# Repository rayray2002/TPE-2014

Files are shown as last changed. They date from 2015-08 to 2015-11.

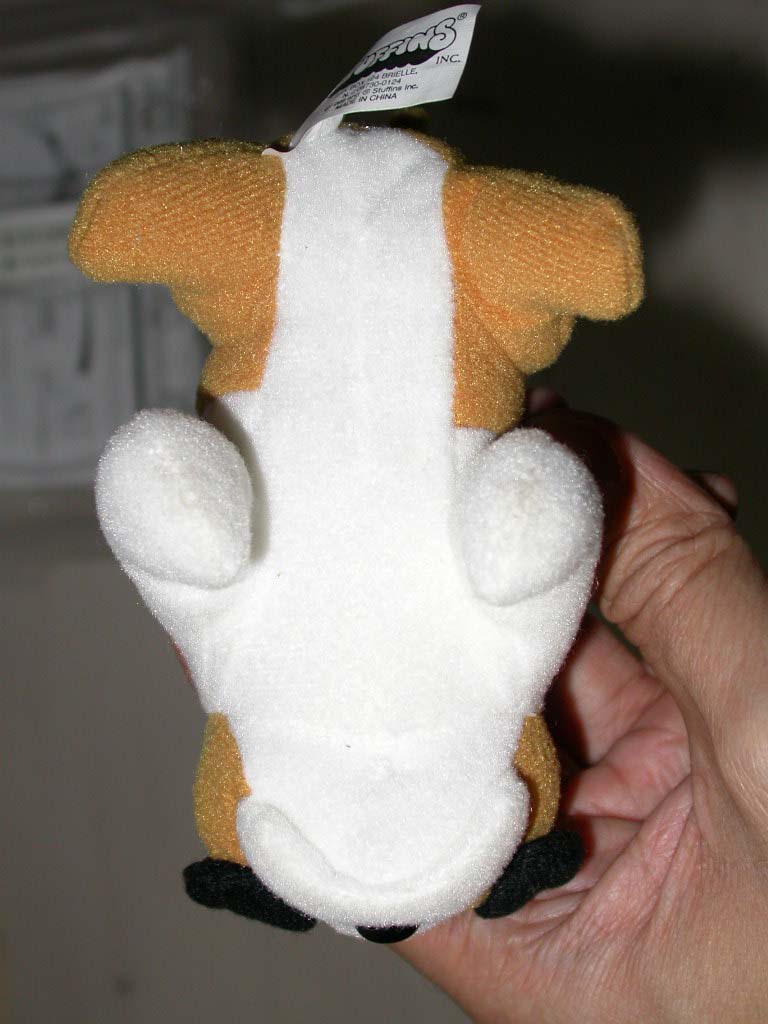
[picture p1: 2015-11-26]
3D/doggie/images/doggie_bottom.jpg

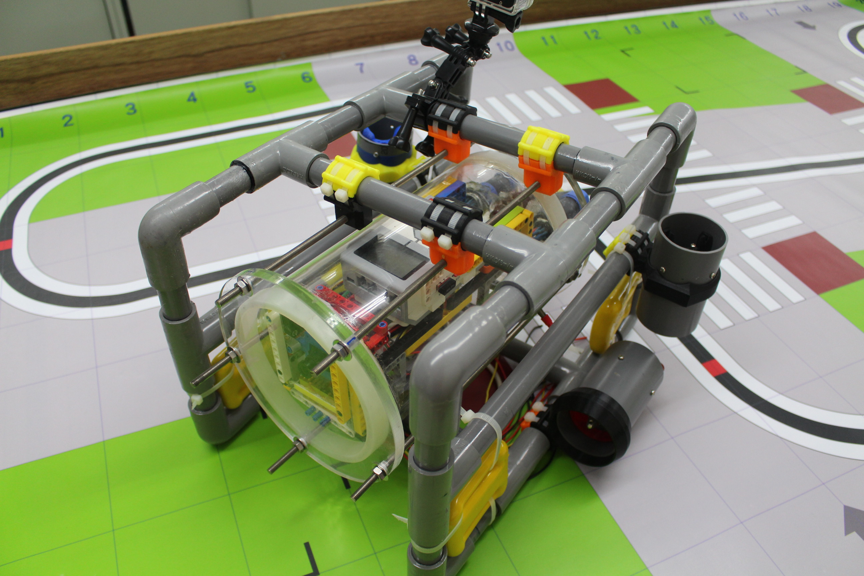
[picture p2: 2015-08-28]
document/images/IMG_3896.JPG

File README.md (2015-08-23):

# TPE-2014

TODO:
1. poster - 3 pages, architecture, include ev3dev, edison, arduino
2. software - pyserial, remote control,
3. hardware 

----
picture  
MINDMAP - 方法論
硬體架構圖
系統架構圖
功能流程圖
電路圖 - ev3

rov照片
intel edison照片
遙控介面圖

重點:
pwm, rc ppm, ev3 pin, 電壓和電流
7407 - 遇到的問題
uart, between ev3 edison, ev3 arduino pro mini
i2c, mpu9150 遇到 RTIMU
intel edison
  webserver
  wsgi
  javascript, html

結構
　　樂高, 3D print, 氣密, 電線安排, pvc管(切,合)？
  pvc管包壓克力管

  遇到的問題

  無法固定
  空間不足

解決

  用3dprinter印基座固定
  用洞洞板把麵包版上的元件焊得更小
  把板子換成arduino pro mini

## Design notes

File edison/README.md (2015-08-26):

UART set GPIO mode
https://communities.intel.com/thread/55790

echo 214 > /sys/class/gpio/export 2>&1
echo high > /sys/class/gpio/gpio214/direction
echo low > /sys/class/gpio/gpio214/direction
 
echo 131 > /sys/class/gpio/export 2>&1
echo mode1 > /sys/kernel/debug/gpio_debug/gpio131/current_pinmux
echo 249 > /sys/class/gpio/export 2>&1
echo high > /sys/class/gpio/gpio249/direction
echo 1 > /sys/class/gpio/gpio249/value
echo 217 > /sys/class/gpio/export 2>&1
echo high > /sys/class/gpio/gpio217/direction
echo 1 > /sys/class/gpio/gpio217/value
echo out > /sys/class/gpio/gpio131/direction
echo 0 > /sys/class/gpio/gpio131/value

echo 130 > /sys/class/gpio/export 2>&1
echo mode1 > /sys/kernel/debug/gpio_debug/gpio130/current_pinmux
echo 248 > /sys/class/gpio/export 2>&1
echo low > /sys/class/gpio/gpio248/direction
echo 0 > /sys/class/gpio/gpio248/value
echo 216 > /sys/class/gpio/export 2>&1
echo in > /sys/class/gpio/gpio216/direction
echo in > /sys/class/gpio/gpio130/direction
 
echo high > /sys/class/gpio/gpio214/direction

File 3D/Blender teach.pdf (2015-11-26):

# Blender教學講義

# Blender新手入門

### 1. 使用說明 2. Blender 介面 3. 使用者選單 4. 視角切換指令 5. 常用快速鍵

# 基礎模型建立

### 1. 新增物件 2. 編輯物件 3. 材質介面 4. 燈光介面 5. 渲染輸出

# 進階建模：高腳杯

### 1. 建立背景參考圖 2. 製作模型 3. 物件編修功能 4. 圖層管理 5. 透明材質 6. 鏡像材質與環境紋理 7. 燈光與陰影設置

# Blender新手入門

# １.使用說明

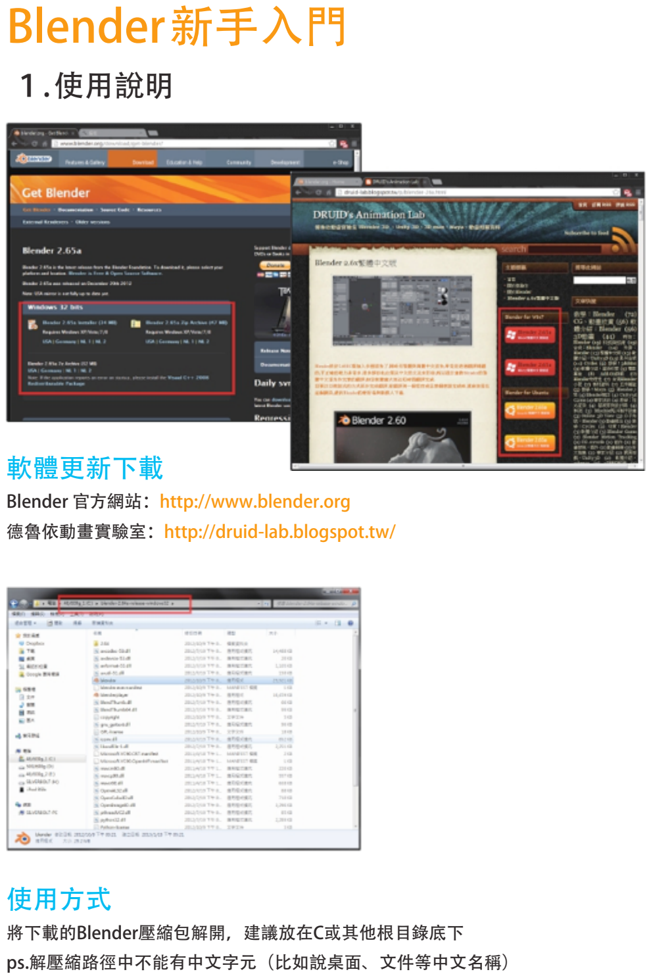
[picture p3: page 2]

## 軟體更新下載

Blender 官方網站：http://www.blender.org德魯依動畫實驗室：http://druid-lab.blogspot.tw/

## 使用方式

將下載的Blender壓縮包解開，建議放在C或其他根目錄底下 ps.解壓縮路徑中不能有中文字元（比如說桌面、文件等中文名稱）

# Blender新手入門

# 2.Blender介面

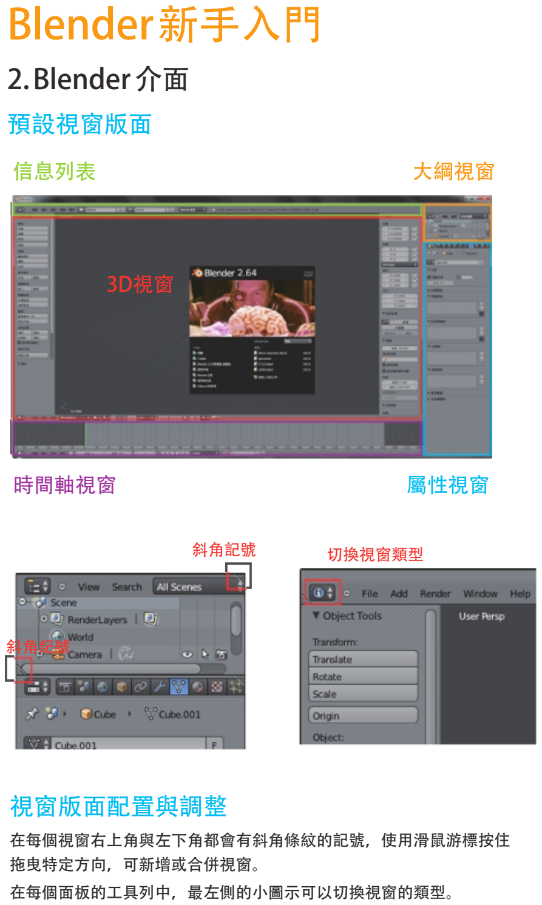
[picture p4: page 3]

## 預設視窗版面

信息列表 | 大綱視窗

### 3D視窗

時間軸視窗 | 屬性視窗
斜角記號 | 切換視窗類型

斜角記號

## 視窗版面配置與調整

在每個視窗右上角與左下角都會有斜角條紋的記號，使用滑鼠游標按住 拖曳特定方向，可新增或合併視窗。
在每個面板的工具列中，最左側的小圖示可以切換視窗的類型。

# Blender新手入門

# 3.使用者選單

## 開啟使用者選單

file（檔案）→ User Preferences（使用者設定）

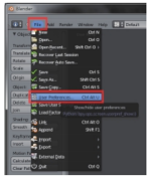
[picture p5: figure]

## 使用者選單設定

中文化設定

System（系統）→ 勾選 International Fonts（多國語言）
→ 選擇 Language（ 語系）→ Traditional Chinese（繁體中文）

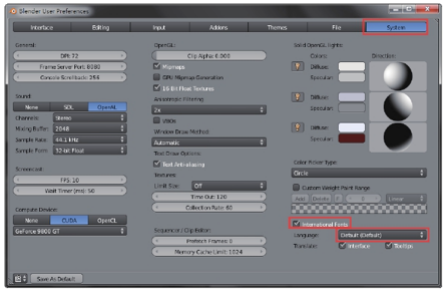
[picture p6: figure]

# Blender新手入門

# ４.視角切換指令

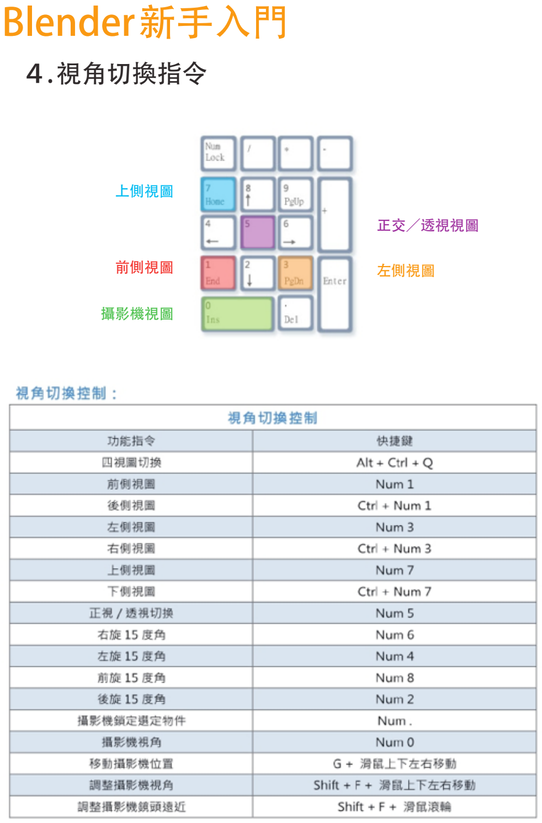
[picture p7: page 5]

上側視圖

前側視圖

攝影機視圖

正交／透視視圖

左側視圖

# Blender新手入門

# ５.常用快速鍵

開新檔案
開啟舊檔
儲存檔案
令存新檔
附加檔案
增加物件選單
複製物件
復原上一動作
重複前一動作
顯示／隱藏視窗工具架
顯示／隱藏視窗屬性選單
選取
移動
旋轉
縮放
單軸向移動、旋轉、縮放
雙軸向移動、旋轉、縮放
合併物件
子父關係
物件／編輯模式切換
全選／取消全選
反選
框選
複選
筆刷選取
增加選取
減少選取
選取環狀邊緣
區域影響切換
實體／線框顯示切換
擠出
刪除
環形切割
橋接點、線
增加點、線、面至游標位置
渲染圖像
顯示／隱藏渲染視窗
移動至圖層

Ｃtrl + N
F1、Ctrl + O
Ctrl + S
F2、Ctrl + Shift + S
Shift + F1
Shift + A
Shift + D
Ctrl + Z
Shift + R
T
N
滑鼠右鍵
G
R
S
啟用G、R、S狀態下，輸入對應的XYZ軸向
啟用G、R、S狀態下，輸入Shift + 不對應的XYZ軸向 Ctrl + J
Ctrl + P
Tab
A
Ctrl + I
輸入B後、滑鼠左鍵拖曳範圍
按住Shift、滑鼠右鍵加選目標
C
按住Ctrl、輸入+號
按住Ctrl、輸入-號
Alt + 滑鼠右鍵選取
O
Z
E
X、Delete
Ctrl + R
F
Ctrl + 滑鼠左鍵指定位置
F12
F11
M

# 基礎模型建立

# 1.新增物件

## 增加選單

信息列 → 增加 → 網面 → 多邊形物件

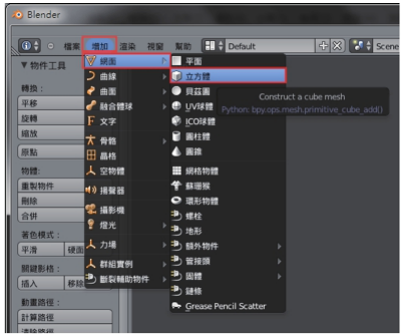
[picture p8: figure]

## 增加選單快速鍵

在3D視窗中輸入 Shift + A 可打開增加選單

# 基礎模型建立

# 2.編輯物件

## 編輯模式

3D視窗工具列 → 物體模式 → 編輯模式

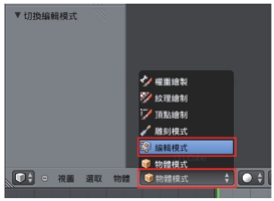
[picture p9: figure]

## 切換模式快速鍵

在3D視窗中輸入 Tab 可切換物體／編輯模式

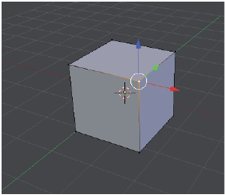
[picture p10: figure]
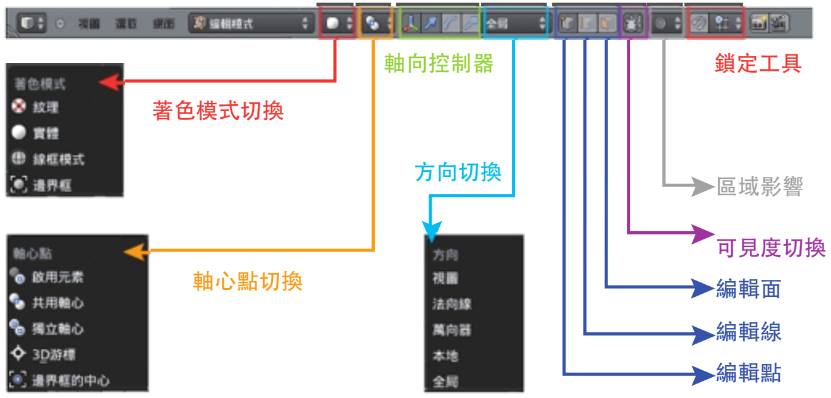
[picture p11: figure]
軸向控制器; 著色模式切換; 方向切換; 軸心點切換; 鎖定工具; 區域影響; 可見度切換; 編輯面; 編輯線; 編輯點

# 基礎模型建立

# 3.材質介面

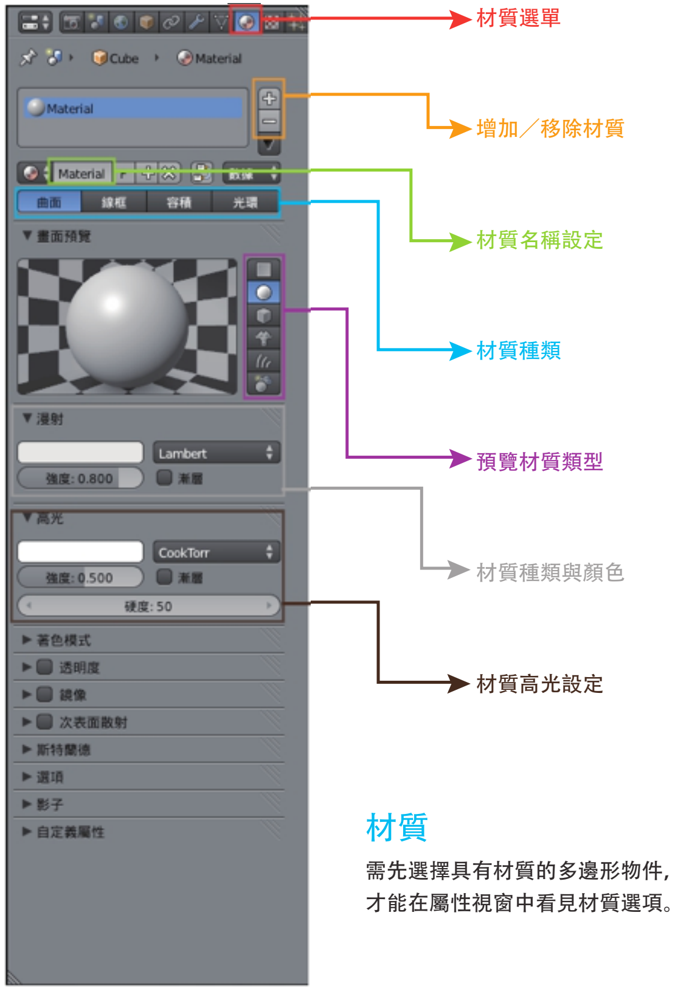
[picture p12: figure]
材質選單; 增加／移除材質; 材質名稱設定; 材質種類; 預覽材質類型; 材質種類與顏色; 材質高光設定; 需先選擇具有材質的多邊形物件，; 才能在屬性視窗中看見材質選項。

# 基礎模型建立

# 4.燈光介面

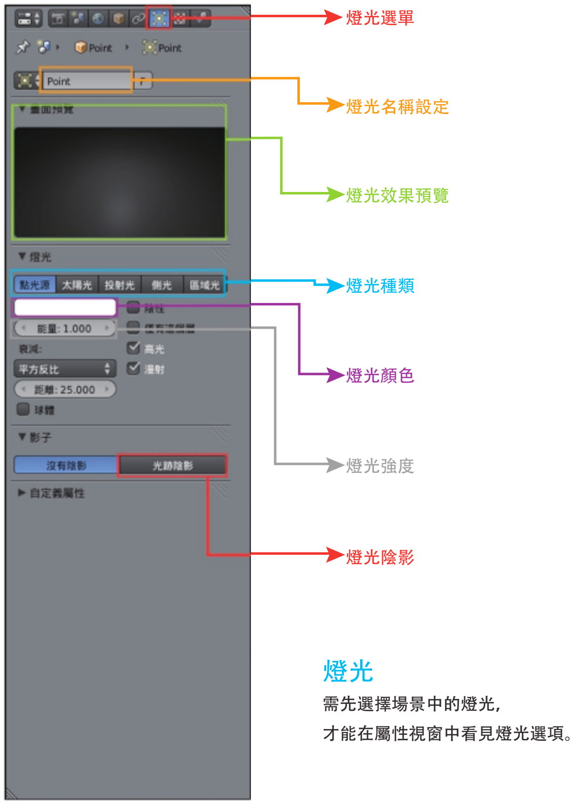
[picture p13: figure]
燈光選單; 燈光名稱設定; 燈光效果預覽; 燈光種類; 燈光顏色; 燈光強度; 燈光陰影; 需先選擇場景中的燈光，; 才能在屬性視窗中看見燈光選項。

# 基礎模型建立

# ５.渲染輸出

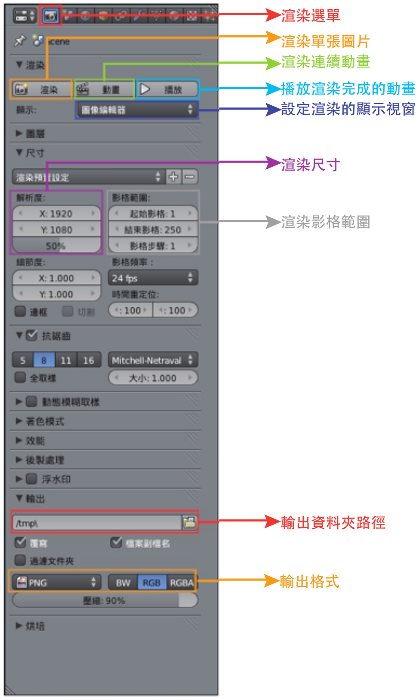
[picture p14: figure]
渲染選單; 渲染單張圖片 渲染連續動畫; 播放渲染完成的動畫 設定渲染的顯示視窗; 渲染尺寸; 渲染影格範圍; 輸出資料夾路徑; 輸出格式

# 進階建模：高腳杯

# 1.建立背景參考圖

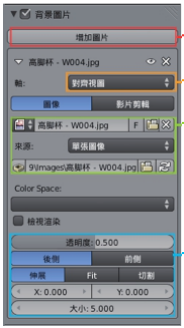
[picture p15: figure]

增加背景圖片

對齊類型

背景圖對應的檔名與資料夾路徑

圖片透明度、位置、大小調整

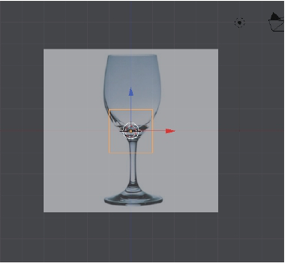
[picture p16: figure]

# 進階建模：高腳杯

# 2.製作模型

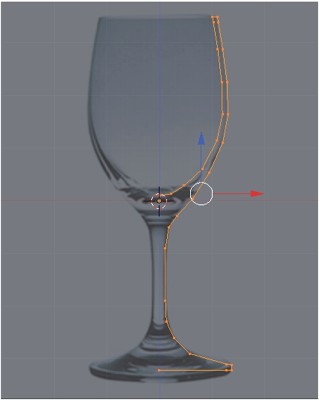
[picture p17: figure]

## 製作外型

在編輯模式中，以Ｘ軸向０為分隔線，製作半個模型的輪廓。

# 進階建模：高腳杯

# 3.物件編修功能

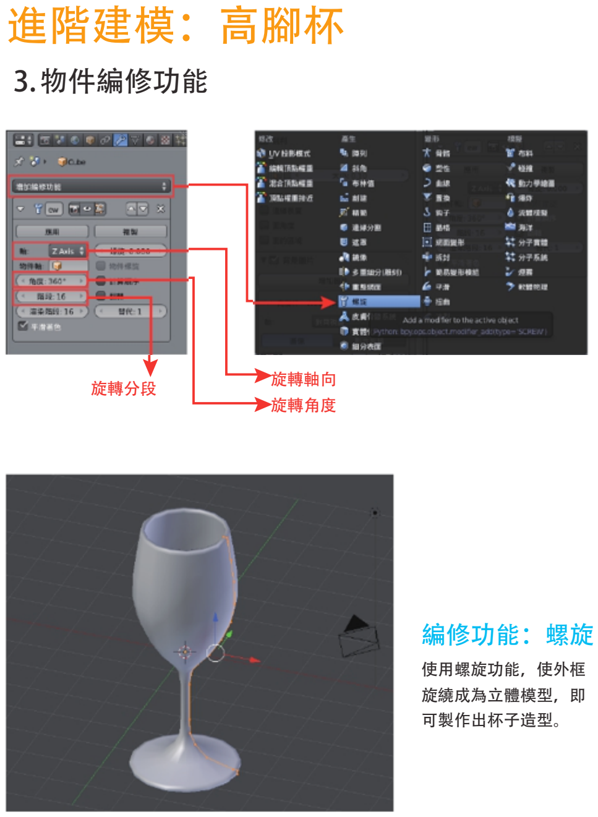
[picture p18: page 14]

旋轉分段 | 旋轉軸向 旋轉角度

## 編修功能：螺旋

使用螺旋功能，使外框
旋繞成為立體模型，即
可製作出杯子造型。

# 進階建模：高腳杯

# ４.圖層管理

圖層

快捷鍵Ｍ可以開啟圖層選單，可將場景中所選取的物件放置於單一或多個圖層， 方便檢視場景以及管理模型。

## 圖層顯示與切換

Blender 的物件模式下，在3D視窗的工具列中有20組圖層可供使用者管理場景中 的物件，使用Shift + 滑鼠左鍵加選圖層，可同時顯示多個圖層中的物件。

## 圖層圖示

黃色圓點 → 圖層中有物件存在
深灰色圖層 → 目前顯示的圖層
淺灰色圖層 → 沒有顯示的圖層

# 進階建模：高腳杯

# ５.透明材質

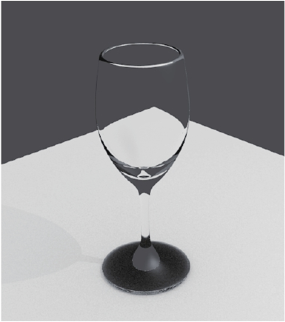
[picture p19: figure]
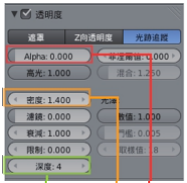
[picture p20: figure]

透明度

折色率

光線穿透程度

## 透明材質

重點在於光跡追蹤的透明（Alpha）、折色率（密度）、穿透程度（深度） 三個數據的調整，其次，濾鏡可以調整玻璃的色彩、光澤的數值可以決定 玻璃的粗糙程度。

# 進階建模：高腳杯

# 6.鏡像材質與環境紋理

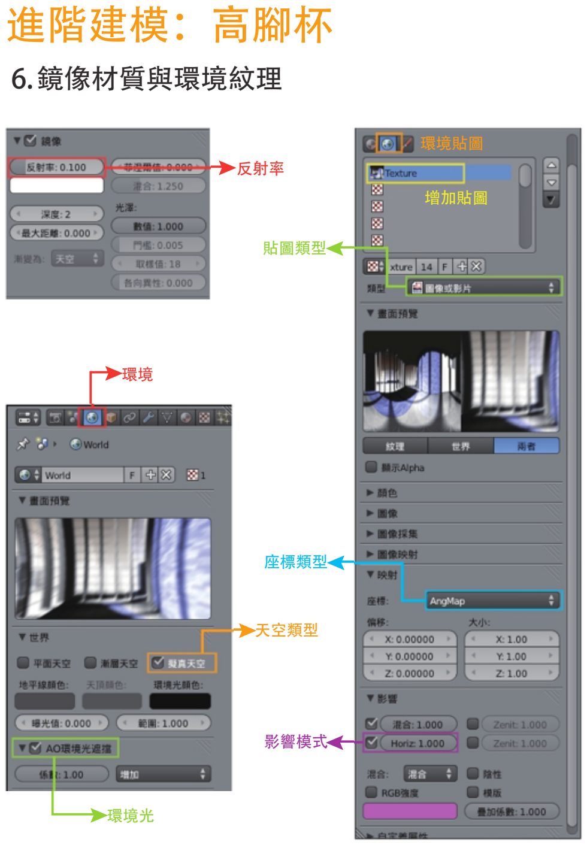
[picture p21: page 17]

環境貼圖
反射率

增加貼圖

貼圖類型

環境

座標類型

天空類型

影響模式

環境光

# 進階建模：高腳杯

# 7.燈光與陰影設置

陰影細節

陰影模糊

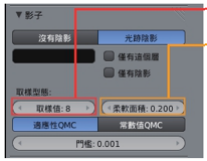
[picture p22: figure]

## 燈光與陰影

陰影可以使成品增添立體感，也可設置多個光源利用光線讓畫面更豐富。

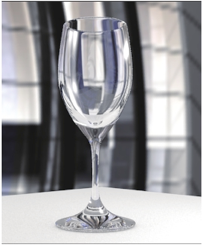
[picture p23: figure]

成品

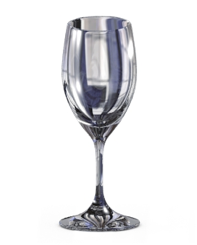
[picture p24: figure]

要注意輸出的格式與選項，尤其是有環境背景的渲染，可節省後製上的麻煩。

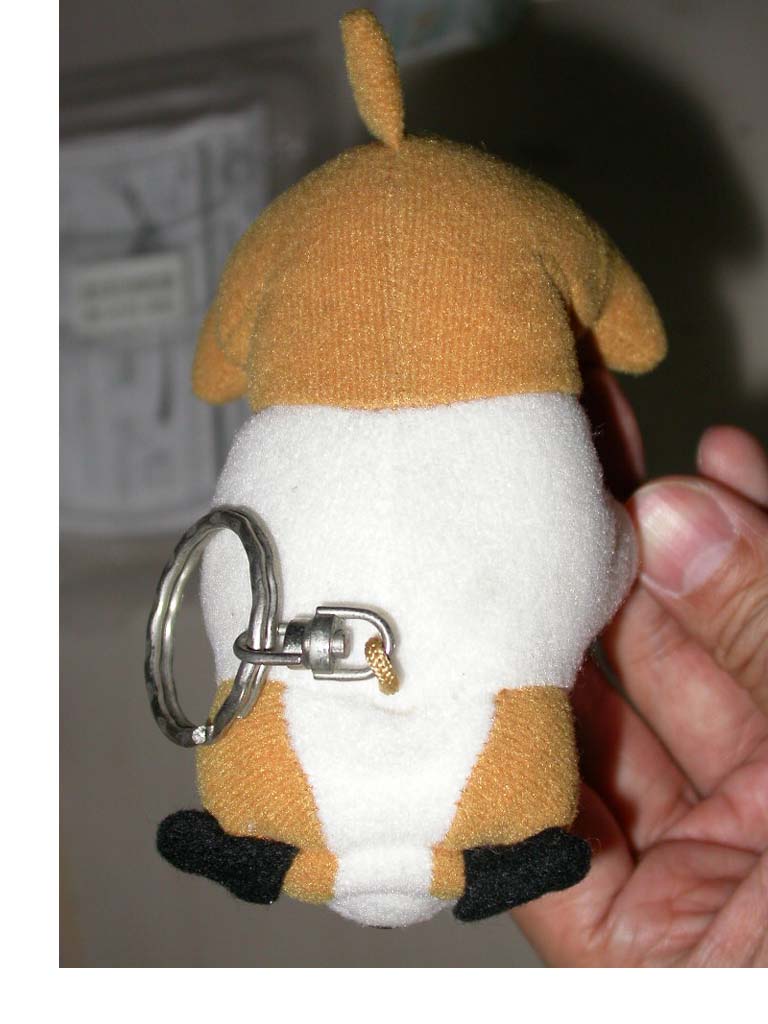
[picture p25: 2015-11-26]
3D/doggie/images/doggie_top.jpg

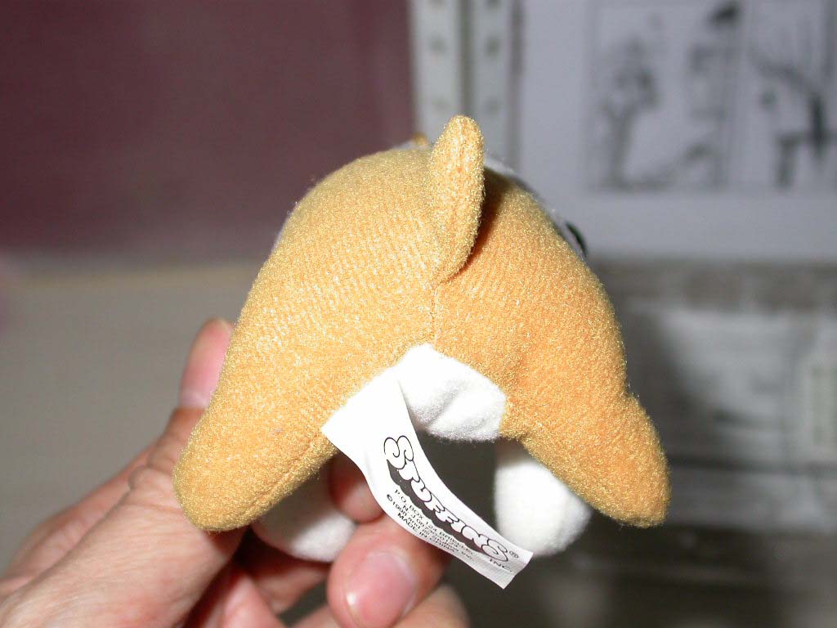
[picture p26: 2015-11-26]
3D/doggie/images/doggie_back.jpg

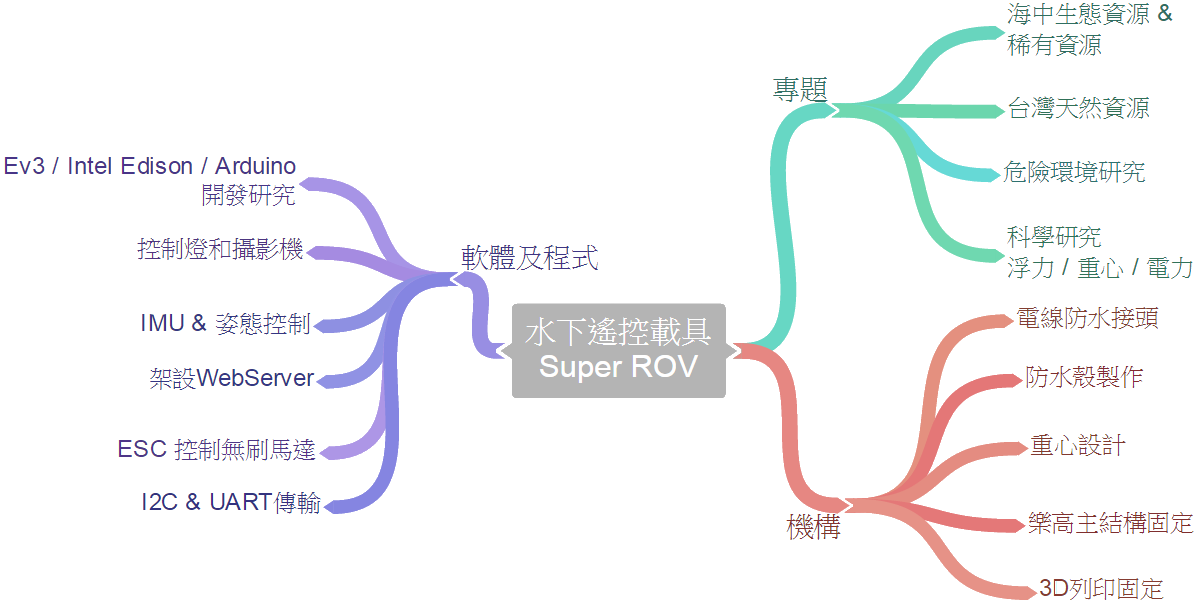
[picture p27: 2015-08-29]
document/images/mindmap_whiteout.png

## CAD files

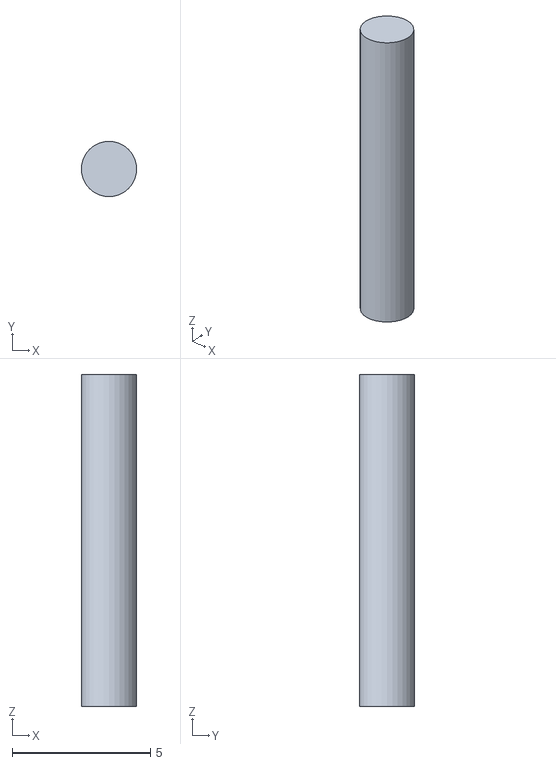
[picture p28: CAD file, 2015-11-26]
3D/BONE.stl
2.00 x 2.00 x 12.0

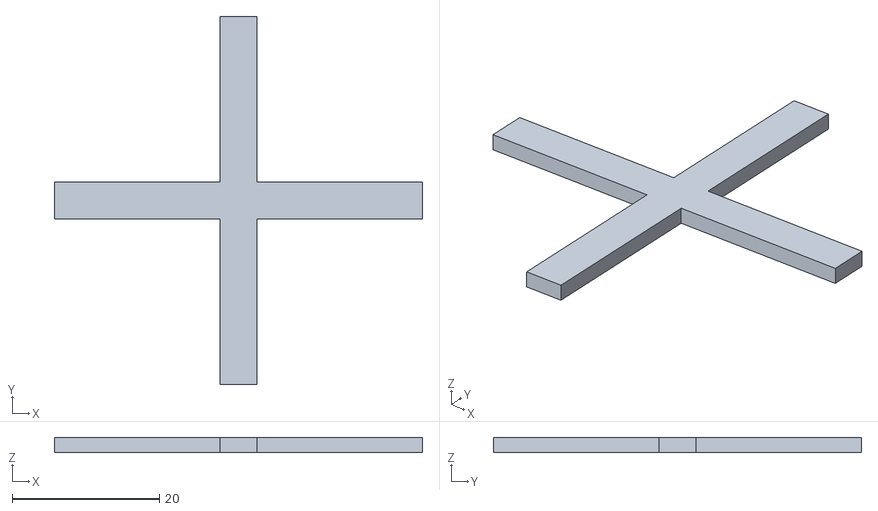
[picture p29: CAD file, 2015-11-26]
3D/cross_test.stl
50.0 x 50.0 x 2.00

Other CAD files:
3D/doggie/doggie_bone.stl
3D/BAYMAX.blend
3D/BONE.blend
3D/doggie/doggie_1.blend
3D/doggie/doggie_2.blend
3D/doggie/doggie_3.blend
3D/doggie/doggie_4.blend
3D/doggie/doggie_bone.blend
3D/pumpkin.blend

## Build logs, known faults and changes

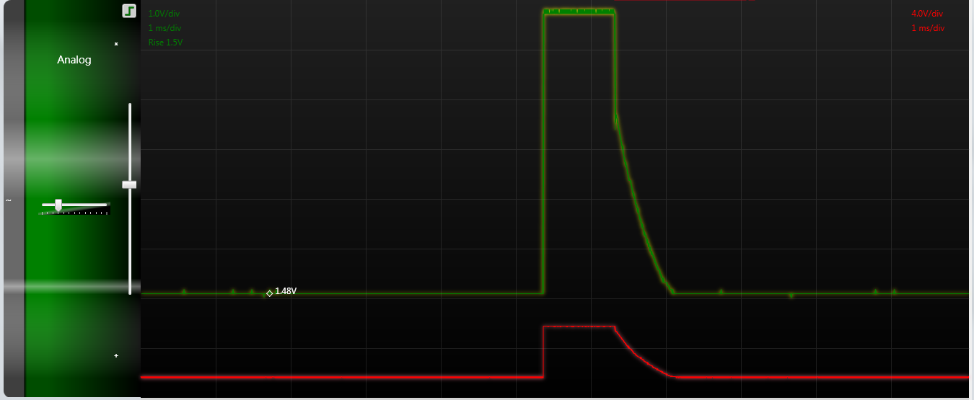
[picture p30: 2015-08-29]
document/images/20ms_problem.png

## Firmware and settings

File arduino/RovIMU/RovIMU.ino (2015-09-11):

#include <Wire.h>
#include "I2Cdev.h"
#include "RTIMUSettings.h"
#include "RTIMU.h"
#include "RTFusionRTQF.h" 
#include "CalLib.h"
#include "Rov.h"
#include <EEPROM.h>
#include <SoftwareSerial.h>
#include <Servo.h>

RTIMU *imu;                                           // the IMU object
RTFusionRTQF fusion;                                  // the fusion object
RTIMUSettings settings;                               // the settings object
Rov rov;

//  DISPLAY_INTERVAL sets the rate at which results are displayed
#define DISPLAY_INTERVAL  100                         // interval between pose displays
#define LIGHT_PIN 13
#define CAMERA_PIN 12

SoftwareSerial mySerial(10, 11); // RX, TX

unsigned long lastDisplay;
unsigned long lastRate;
int sampleCount;

#define MOTOR_L 0
#define MOTOR_R 1
#define MOTOR_LU 2
#define MOTOR_RU 3
#define NO_SERVO 4

Servo motors[4];
int fixedServoValues[4];
boolean fixed = false;

void writeAll(int s) {
  for(int i=0; i<4; i++)
  motors[i].writeMicroseconds(s); 
}

void setupMotors() {
  motors[0].attach(6); //L
  motors[1].attach(9); //R
  motors[2].attach(3); //LU
  motors[3].attach(5); //RU
  
  if(DEBUG) Serial.println("ESC calibrate start - stick low");
  writeAll(1000);
  delay(5000);
  if(DEBUG) Serial.println("ESC calibrate #2 - stick high");
  writeAll(2000);
  delay(1200);
  if(DEBUG) Serial.println("ESC calibrate #3 - stick low");
  writeAll(1000);
  delay(1200);
  if(DEBUG) Serial.println("ESC calibrate #4 - stick middle - long beep");
  writeAll(1500);
  delay(3000); //hear 3 beeps to enter RC neturel mode 
  if(DEBUG) Serial.println("ESC calibrate end");
}

void setup() 
{
    if(DEBUG) Serial.print("setup() #1");
    Serial.begin(SERIAL_PORT_SPEED);
    mySerial.begin(38400);
    pinMode(LIGHT_PIN, OUTPUT);
    pinMode(CAMERA_PIN, OUTPUT);
    
    setupMotors();
    
    rov = Rov();
    rov.init();
    
    int errcode;
    Wire.begin();
    imu = RTIMU::createIMU(&settings);                        // create the imu object
  
    if(DEBUG) Serial.print("ArduinoIMU starting using device ");
    if(DEBUG) Serial.println(imu->IMUName());
    if ((errcode = imu->IMUInit()) < 0) {
        if(DEBUG) {
            Serial.print("Failed to init IMU: "); 
            Serial.println(errcode);
        }
    }
    if (imu->getCalibrationValid())
        if(DEBUG) Serial.println("Using compass calibration");
    else
        if(DEBUG) Serial.println("No valid compass calibration data");
    // Slerp power controls the fusion and can be between 0 and 1
    // 0 means that only gyros are used, 1 means that only accels/compass are used
    // In-between gives the fusion mix.
    fusion.setSlerpPower(0.3);
    fusion.setGyroEnable(true);
    fusion.setAccelEnable(true);
    fusion.setCompassEnable(true);
    if(DEBUG) Serial.print("setup() #N");
}

void sendGyroData(RTVector3 p ) {
#ifdef EV3_COMM
    mySerial.write( 'a' );
    short x = p.x() * RTMATH_RAD_TO_DEGREE * 100;
    mySerial.write( (byte)x );
    mySerial.write( (byte)(x >> 8) );
    short y = p.y() * RTMATH_RAD_TO_DEGREE * 100;
    mySerial.write( (byte)y );
    mySerial.write( (byte)(y >> 8) );
    short z = p.z() * RTMATH_RAD_TO_DEGREE * 100;
    mySerial.write( (byte)z );
    mySerial.write( (byte)(z >> 8) );
    mySerial.write( '\n' );
#endif 
}
    
char buffer[64];
int pos = 0;
void processSerial(int index, int len) {
  char s[len+1];
  
  for(int i=0; i< len; i++)
    s[i] = buffer[i+index +1];
  s[len] = 0;
    
  Serial.print(">>");
  Serial.println(s);
  
  if( strcmp("init", s) == 0) {
  }
  else if( strcmp("camera_on", s) == 0) {
    digitalWrite(CAMERA_PIN, HIGH);
  }
  else if( strcmp("camera_off", s) == 0) {
    digitalWrite(CAMERA_PIN, LOW);
  }
  else if( strcmp("light_on", s) == 0) {
    digitalWrite(LIGHT_PIN, HIGH);
  }
  else if( strcmp("light_off", s) == 0) {
    digitalWrite(LIGHT_PIN, LOW);
  }
  else if( strcmp("forward", s) == 0) {
    rov.forward();
    fixed = true;
    fixedServoValues[MOTOR_L] = fixedServoValues[MOTOR_R] = 1500 + 100.0 * rov.power;
  }
  else if( strcmp("backward", s) == 0) {
    rov.backward();
    fixedServoValues[MOTOR_L] = fixedServoValues[MOTOR_R] = 1500 + 100.0 * rov.power;
  }
  else if( strcmp("stop", s) == 0) {
    rov.stop();
    fixed = false;
    fixedServoValues[MOTOR_L] = fixedServoValues[MOTOR_R] = 1500;
    fixedServoValues[MOTOR_LU] = fixedServoValues[MOTOR_RU] = 1500;
  }
  else if( strcmp("right", s) == 0) {
    rov.right();
    fixed = true;
    fixedServoValues[MOTOR_L] = 1500; 
    fixedServoValues[MOTOR_R] = 1600;
    
  }
  else if( strcmp("left", s) == 0) {
    rov.left();
    fixed = true;
    fixedServoValues[MOTOR_L] = 1600; 
    fixedServoValues[MOTOR_R] = 1500;
  }
  else if( strcmp("up", s) == 0) {
    rov.up();
    fixed = true;
    fixedServoValues[MOTOR_LU] = 1600; 
    fixedServoValues[MOTOR_RU] = 1600;
    }
  else if( strcmp("down", s) == 0) {
    rov.down();
    fixed = true;
    fixedServoValues[MOTOR_LU] = 1400; 
    fixedServoValues[MOTOR_RU] = 1400;
  }
  else if( strncmp("power", s, 5) == 0 ) {
    char t[4];
    for(int m=0; m <= 3; m++)
      t[m] = s[m + 5];
    t[3] = 0;
    byte p = atoi(t);
    rov.setPower(p / 100.0);
  }
}

void readSerial() {
  boolean readFlag = false;
  while(mySerial.available() > 0){
    char c = mySerial.read();
    buffer[pos++] = c;
    readFlag = true;
  }
  if(pos==64) pos = 0; //full
  
  if(readFlag == true) {
    for(int i = 0; i < pos; i++) {
      if(buffer[i] == 'a') {
        for(int j = i; j < pos; j++) {
          if(buffer[j] == '\n') {
            buffer[j] = '\0';
            processSerial(i+1, j-i); //skip a
            pos = 0;
            return;
          }
        }
      }
    }
  }
}

RTVector3 readIMU() {
    int loopCount = 1;
    RTVector3 pose;
    
    while (imu->IMURead()) {
        if (++loopCount >= 20) continue;
        fusion.newIMUData(imu->getGyro(), imu->getAccel(), imu->getCompass(), imu->getTimestamp());
        pose = fusion.getFusionPose();
        rov.reportIMU(pose.x() * RTMATH_RAD_TO_DEGREE, pose.y() * RTMATH_RAD_TO_DEGREE, pose.z() * RTMATH_RAD_TO_DEGREE);
    }
    
    return pose;
}

void controlMotors() {
  for(int i=0; i<4; i++) {
    int v = 0;
    if(fixed) v = fixedServoValues[i];
    else v = rov.servoValues[i];
    motors[i].writeMicroseconds(v);
#if 0
      Serial.print("T");
      Serial.print(i);
      Serial.print(":");
      Serial.print(v);
      Serial.print('\t');
#endif
  }
  //Serial.print('\n');
}

void loop()
{  
  //receive command
  readSerial();
  
  //read IMU, set sensor
  RTVector3 pose = readIMU();
  
  //PID control
  //output motors
  rov.step(); 
  controlMotors();
  
  //report gyro
  sendGyroData(pose);
}

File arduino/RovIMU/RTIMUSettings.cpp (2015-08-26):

////////////////////////////////////////////////////////////////////////////
//
//  This file is part of RTIMULib-Arduino
//
//  Copyright (c) 2014-2015, richards-tech
//
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
#include "RTIMUSettings.h"

#if defined(MPU9150_68) || defined(MPU9150_69)
#include "RTIMUMPU9150.h"
#endif

#if defined(MPU9250_68) || defined(MPU9250_69)
#include "RTIMUMPU9250.h"
#endif

#if defined(LSM9DS0_6a) || defined(LSM9DS0_6b)
#include "RTIMULSM9DS0.h"
#endif

#if defined(GD20HM303D_6a) || defined(GD20HM303D_6b)
#include "RTIMUGD20HM303D.h"
#endif

#if defined(GD20M303DLHC_6a) || defined(GD20M303DLHC_6b)
#include "RTIMUGD20M303DLHC.h"
#endif

#if defined(GD20HM303DLHC_6a) || defined(GD20HM303DLHC_6b)
#include "RTIMUGD20HM303DLHC.h"
#endif

#if defined(BMP180)
#include "RTPressureBMP180.h"
#endif

#if defined(LPS25H_5c) || defined (LPS25H_5d)
#include "RTPressureLPS25H.h"
#endif

#if defined(MS5611_76) || defined (MS5611_77)
#include "RTPressureMS5611.h"
#endif

#define RATE_TIMER_INTERVAL 2

RTIMUSettings::RTIMUSettings()
{
    //  preset general defaults

    m_imuType = -1;
    m_I2CSlaveAddress = 0;

#ifdef MPU9150_68
    //  MPU9150 defaults

    m_MPU9150GyroAccelSampleRate = 50;
    m_MPU9150CompassSampleRate = 25;
    m_MPU9150GyroAccelLpf = MPU9150_LPF_20;
    m_MPU9150GyroFsr = MPU9150_GYROFSR_1000;
    m_MPU9150AccelFsr = MPU9150_ACCELFSR_8;
    m_imuType = RTIMU_TYPE_MPU9150;
    m_I2CSlaveAddress = MPU9150_ADDRESS0;
#endif

#ifdef MPU9150_69
    //  MPU9150 defaults

    m_MPU9150GyroAccelSampleRate = 50;
    m_MPU9150CompassSampleRate = 25;
    m_MPU9150GyroAccelLpf = MPU9150_LPF_20;
    m_MPU9150GyroFsr = MPU9150_GYROFSR_1000;
    m_MPU9150AccelFsr = MPU9150_ACCELFSR_8;
    m_imuType = RTIMU_TYPE_MPU9150;
    m_I2CSlaveAddress = MPU9150_ADDRESS1;
#endif

#ifdef MPU9250_68
    //  MPU9250 defaults

    m_MPU9250GyroAccelSampleRate = 80;
    m_MPU9250CompassSampleRate = 40;
    m_MPU9250GyroLpf = MPU9250_GYRO_LPF_41;
    m_MPU9250AccelLpf = MPU9250_ACCEL_LPF_41;
    m_MPU9250GyroFsr = MPU9250_GYROFSR_1000;
    m_MPU9250AccelFsr = MPU9250_ACCELFSR_8;
    m_I2CSlaveAddress = MPU9250_ADDRESS0;
#endif

#ifdef MPU9250_69
    //  MPU9250 defaults

    m_MPU9250GyroAccelSampleRate = 80;
    m_MPU9250CompassSampleRate = 40;
    m_MPU9250GyroLpf = MPU9250_GYRO_LPF_41;
    m_MPU9250AccelLpf = MPU9250_ACCEL_LPF_41;
    m_MPU9250GyroFsr = MPU9250_GYROFSR_1000;
    m_MPU9250AccelFsr = MPU9250_ACCELFSR_8;
    m_I2CSlaveAddress = MPU9250_ADDRESS1;
#endif

#ifdef LSM9DS0_6a
    //  LSM9DS0 defaults

    m_LSM9DS0GyroSampleRate = LSM9DS0_GYRO_SAMPLERATE_95;
    m_LSM9DS0GyroBW = LSM9DS0_GYRO_BANDWIDTH_1;
    m_LSM9DS0GyroHpf = LSM9DS0_GYRO_HPF_4;
    m_LSM9DS0GyroFsr = LSM9DS0_GYRO_FSR_500;

    m_LSM9DS0AccelSampleRate = LSM9DS0_ACCEL_SAMPLERATE_50;
    m_LSM9DS0AccelFsr = LSM9DS0_ACCEL_FSR_8;
    m_LSM9DS0AccelLpf = LSM9DS0_ACCEL_LPF_50;

    m_LSM9DS0CompassSampleRate = LSM9DS0_COMPASS_SAMPLERATE_50;
    m_LSM9DS0CompassFsr = LSM9DS0_COMPASS_FSR_2;

    m_imuType = RTIMU_TYPE_LSM9DS0;
    m_I2CSlaveAddress = LSM9DS0_GYRO_ADDRESS0;

#endif

#ifdef LSM9DS0_6b
    //  LSM9DS0 defaults

    m_LSM9DS0GyroSampleRate = LSM9DS0_GYRO_SAMPLERATE_95;
    m_LSM9DS0GyroBW = LSM9DS0_GYRO_BANDWIDTH_1;
    m_LSM9DS0GyroHpf = LSM9DS0_GYRO_HPF_4;
    m_LSM9DS0GyroFsr = LSM9DS0_GYRO_FSR_500;

    m_LSM9DS0AccelSampleRate = LSM9DS0_ACCEL_SAMPLERATE_50;
    m_LSM9DS0AccelFsr = LSM9DS0_ACCEL_FSR_8;
    m_LSM9DS0AccelLpf = LSM9DS0_ACCEL_LPF_50;

    m_LSM9DS0CompassSampleRate = LSM9DS0_COMPASS_SAMPLERATE_50;
    m_LSM9DS0CompassFsr = LSM9DS0_COMPASS_FSR_2;

    m_imuType = RTIMU_TYPE_LSM9DS0;
    m_I2CSlaveAddress = LSM9DS0_GYRO_ADDRESS1;

#endif

#ifdef GD20HM303D_6a
    //  GD20HM303D defaults

    m_GD20HM303DGyroSampleRate = L3GD20H_SAMPLERATE_50;
    m_GD20HM303DGyroBW = L3GD20H_BANDWIDTH_1;
    m_GD20HM303DGyroHpf = L3GD20H_HPF_4;
    m_GD20HM303DGyroFsr = L3GD20H_FSR_500;

    m_GD20HM303DAccelSampleRate = LSM303D_ACCEL_SAMPLERATE_50;
    m_GD20HM303DAccelFsr = LSM303D_ACCEL_FSR_8;
    m_GD20HM303DAccelLpf = LSM303D_ACCEL_LPF_50;

    m_GD20HM303DCompassSampleRate = LSM303D_COMPASS_SAMPLERATE_50;
    m_GD20HM303DCompassFsr = LSM303D_COMPASS_FSR_2;

    m_imuType = RTIMU_TYPE_GD20HM303D;
    m_I2CSlaveAddress = L3GD20H_ADDRESS0;
#endif

#ifdef GD20HM303D_6b
    //  GD20HM303D defaults

    m_GD20HM303DGyroSampleRate = L3GD20H_SAMPLERATE_50;
    m_GD20HM303DGyroBW = L3GD20H_BANDWIDTH_1;
    m_GD20HM303DGyroHpf = L3GD20H_HPF_4;
    m_GD20HM303DGyroFsr = L3GD20H_FSR_500;

    m_GD20HM303DAccelSampleRate = LSM303D_ACCEL_SAMPLERATE_50;
    m_GD20HM303DAccelFsr = LSM303D_ACCEL_FSR_8;
    m_GD20HM303DAccelLpf = LSM303D_ACCEL_LPF_50;

    m_GD20HM303DCompassSampleRate = LSM303D_COMPASS_SAMPLERATE_50;
    m_GD20HM303DCompassFsr = LSM303D_COMPASS_FSR_2;

    m_imuType = RTIMU_TYPE_GD20HM303D;
    m_I2CSlaveAddress = L3GD20H_ADDRESS1;
#endif
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

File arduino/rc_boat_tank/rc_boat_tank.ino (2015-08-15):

//5/25 mpu 9150 Serial fix




#include <SoftwareSerial.h>
#include <MsTimer2.h>
#include <Servo.h>

#define LED_L 13
#define LED_R 12

Servo r_motor;
Servo l_motor;

SoftwareSerial mySerial(10, 11);

typedef enum {
  CMD_Forward,
  CMD_Backward,
  CMD_Stop,
} Command;

typedef enum {
  Forward_On,
  Forward_Off,
  Stop,
  Backward_Back,
  Backward_Netural,
  Backward_On,
  Backward_Off,
} MotorState;

typedef struct {
  Command cmd;
  MotorState state;
  unsigned long timestamp;
  int duty_cycle; // 0~100%
} Motor;

int level = 20;
int l_level = 20;
int r_level = 20;
int Start;
int value = 10;
Motor motorL, motorR;

void timerIsr();

void setup() 
{
  Serial.begin(9600);
  mySerial.begin(9600);
  //mySerial.begin(9600);
  stop();
  initMotor();
  initISR();
  Serial.println("ready...");
  //mySerial.println("ready...");
}

void initMotor() {
  pinMode(LED_L, OUTPUT);
  pinMode(LED_R, OUTPUT);  
  r_motor.attach(5);
  l_motor.attach(6);

}
void initISR() {
  MsTimer2::set(10, timerIsr); // 10ms period
  MsTimer2::start();
}

int count = 0;
void loop()
{
  motorL.duty_cycle = 90;
  motorR.duty_cycle = 90;
  if (mySerial.available()) {
    count = 0;
    int raw = mySerial.read();
    //Serial.println(raw);
    if(raw != value) {
      value = raw;
      if(value == '1') 
      {
        R_forward();
      }
      else if(value == '2') 
      {
        R_backward();
      }
      else if(value == '3') 
      {
        L_forward();
      }
      else if(value == '4')
      {
        L_backward();
      }
      else if(value == '0')
      {
        stop();
      }
    }
  }
  else {
    count++;
    if(count == 800) {
      value = 100;
      //stop();
    }  
  }
} //end of loop

void R_forward()
{
  Serial.println("R_forward");
  motorR.timestamp = millis();
  motorR.cmd = CMD_Forward;
  motorR.state = Forward_On;
}

void R_backward()
{
  Serial.println("R_backward");
  motorR.timestamp = millis();
  motorR.cmd = CMD_Backward;
  motorR.state = Backward_On;
}

void L_forward()
{
  Serial.println("L_forward");
  motorL.timestamp = millis();
  motorL.cmd = CMD_Forward;
  motorL.state = Forward_On;
}

void L_backward()
{
  Serial.println("L_backward");
  motorL.timestamp = millis();
  motorL.cmd = CMD_Backward;
  motorL.state = Backward_On;
}
void stop()
{
  Serial.println("stop");
  r_motor.writeMicroseconds(1500);
  l_motor.writeMicroseconds(1500);
  motorL.cmd = CMD_Stop;
  motorL.state = Stop;
  motorR.cmd = CMD_Stop;
  motorR.state = Stop;
}
void checkMotor(Motor* motor);

void timerIsr(){
  checkMotorL();
  checkMotorR();
}

void changeValue(int* value) {
  *value = 20;
}
void checkMotorL() { 
    if(motorL.cmd == CMD_Forward) {
      if(motorL.state == Forward_On && motorL.duty_cycle < 100) {
        if( (millis() - motorL.timestamp) > motorL.duty_cycle*10) {
          digitalWrite( 13, LOW);
          l_motor.writeMicroseconds(1500);
          motorL.timestamp = millis();
          motorL.state = Forward_Off;
        }
      }
      
      if(motorL.state == Forward_Off && motorL.duty_cycle > 0) {
        if( (millis() - motorL.timestamp) > (100-motorL.duty_cycle)*10) {
          digitalWrite( 13, HIGH);
          l_motor.writeMicroseconds(1540);
          motorL.timestamp = millis();
          motorL.state = Forward_On;
        }
      }
    }
    
    if(motorL.cmd == CMD_Backward) {
      if(motorL.state == Backward_On && motorL.duty_cycle < 100) {
        if( (millis() - motorL.timestamp) > motorL.duty_cycle*10) {
          digitalWrite( 13, LOW);
          l_motor.writeMicroseconds(1500);
          motorL.timestamp = millis();
          motorL.state = Backward_Off;
        }
      }
      
      if(motorL.state == Backward_Off && motorL.duty_cycle > 0) {
        if( (millis() - motorL.timestamp) > (100-motorL.duty_cycle)*10) {
          digitalWrite( 13, HIGH);
          l_motor.writeMicroseconds(1200);
          motorL.timestamp = millis();
          motorL.state = Backward_On;
        }
      }
    }
    if(motorL.cmd == CMD_Stop) {
      digitalWrite( 13, LOW);
      l_motor.writeMicroseconds(1500);
    }
}

void checkMotorR() { 
    if(motorR.cmd == CMD_Forward) {
      if(motorR.state == Forward_On && motorR.duty_cycle < 100) {
        if( (millis() - motorR.timestamp) > motorR.duty_cycle*10) {
          digitalWrite( 12, LOW);
          r_motor.writeMicroseconds(1500);
          motorR.timestamp = millis();
          motorR.state = Forward_Off;
        }
      }
      
      if(motorR.state == Forward_Off && motorR.duty_cycle > 0) {
        if( (millis() - motorR.timestamp) > (100-motorR.duty_cycle)*10) {
          digitalWrite( 12, HIGH);
          r_motor.writeMicroseconds(1540);
          motorR.timestamp = millis();
          motorR.state = Forward_On;
        }
      }
    }
    
    if(motorR.cmd == CMD_Backward) {
      if(motorR.state == Backward_On && motorR.duty_cycle < 100) {
        if( (millis() - motorR.timestamp) > motorR.duty_cycle*10) {
          digitalWrite( 12, LOW);
          r_motor.writeMicroseconds(1500);
          motorR.timestamp = millis();
          motorR.state = Backward_Off;
        }
      }
      
      if(motorR.state == Backward_Off && motorR.duty_cycle > 0) {
        if( (millis() - motorR.timestamp) > (100-motorR.duty_cycle)*10) {
          digitalWrite( 12, HIGH);
          r_motor.writeMicroseconds(1200);
          motorR.timestamp = millis();
          motorR.state = Backward_On;
        }
      }
    }
    if(motorR.cmd == CMD_Stop) {
      digitalWrite( 12, LOW);
      r_motor.writeMicroseconds(1500);
    }
}

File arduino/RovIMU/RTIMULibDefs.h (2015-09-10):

////////////////////////////////////////////////////////////////////////////
//
//  This file is part of RTIMULib-Arduino
//
//  Copyright (c) 2014-2015, richards-tech
//
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
#ifndef _RTIMULIBDEFS_H
#define	_RTIMULIBDEFS_H

#include "RTMath.h"
#include "RTPressureDefs.h"

//  IMU enable defs - only one should be enabled, the rest commented out

//#define MPU9150_68                      // MPU9150 at address 0x68
//#define MPU9150_69                      // MPU9150 at address 0x69
//#define MPU9250_68                      // MPU9250 at address 0x68
#define MPU9250_69                      // MPU9250 at address 0x69
//#define LSM9DS0_6a                      // LSM9DS0 at address 0x6a
//#define LSM9DS0_6b                      // LSM9DS0 at address 0x6b
//#define GD20HM303D_6a                   // GD20H + M303D at address 0x6a
//#define GD20HM303D_6b                   // GD20H + M303D at address 0x6b
//#define GD20HM303DLHC_6a                // GD20H + M303DLHC at address 0x6a
//#define GD20HM303DLHC_6b                // GD20H + M303DLHC at address 0x6b
//#define GD20M303DLHC_6a                 // GD20 + M303DLHC at address 0x6a
//#define GD20M303DLHC_6b                 // GD20 + M303DLHC at address 0x6b

//  IMU type codes

#define RTIMU_TYPE_MPU9150                  1                   // InvenSense MPU9150
#define RTIMU_TYPE_LSM9DS0                  2                   // STM LSM9DS0 (eg Sparkfun IMU)
#define RTIMU_TYPE_GD20HM303D               3                   // STM L3GD20H/LSM303D (Pololu Altimu)
#define RTIMU_TYPE_GD20M303DLHC             4                   // STM L3GD20/LSM303DHLC (old Adafruit IMU)
#define RTIMU_TYPE_MPU9250                  5                   // InvenSense MPU9250
#define RTIMU_TYPE_GD20HM303DLHC            6                   // STM L3GD20H/LSM303DHLC (new Adafruit IMU)

//  Pressure enable defs - only one should be enabled, the rest commented out

//#define BMP180                              // BMP180
//#define LPS25H_5c                           // LPS25H at standard address
//#define LPS25H_5d                           // LPS25H at option address
//#define MS5611_76                           // MS5611 at standard address
//#define MS5611_77                           // MS5611 at option address

//  IMU Axis rotation defs
//
//  These allow the IMU to be virtually repositioned if it is in a non-standard configuration
//  Standard configuration is X pointing at north, Y pointing east and Z pointing down
//  with the IMU horizontal. There are 24 different possible orientations as defined
//  below. Setting the axis rotation code to non-zero values performs the repositioning.
//
//  Uncomment the one required

//#define RTIMU_XNORTH_YEAST              0                   // this is the default identity matrix
//#define RTIMU_XEAST_YSOUTH              1
//#define RTIMU_XSOUTH_YWEST              2
#define RTIMU_XWEST_YNORTH              3
//#define RTIMU_XNORTH_YWEST              4
//#define RTIMU_XEAST_YNORTH              5
//#define RTIMU_XSOUTH_YEAST              6
//#define RTIMU_XWEST_YSOUTH              7
//#define RTIMU_XUP_YNORTH                8
//#define RTIMU_XUP_YEAST                 9
//#define RTIMU_XUP_YSOUTH                  10
//#define RTIMU_XUP_YWEST                 11
//#define RTIMU_XDOWN_YNORTH              12
//#define RTIMU_XDOWN_YEAST               13
//#define RTIMU_XDOWN_YSOUTH              14
//#define RTIMU_XDOWN_YWEST               15
//#define RTIMU_XNORTH_YUP                16
//#define RTIMU_XEAST_YUP                 17
//#define RTIMU_XSOUTH_YUP                18
//#define RTIMU_XWEST_YUP                 19
//#define RTIMU_XNORTH_YDOWN              20
//#define RTIMU_XEAST_YDOWN               21
//#define RTIMU_XSOUTH_YDOWN              22
//#define RTIMU_XWEST_YDOWN               23

#endif // _RTIMULIBDEFS_H

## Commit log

2015-08-18 add pwm image
2015-08-23 UART working between MPU9150 & python
